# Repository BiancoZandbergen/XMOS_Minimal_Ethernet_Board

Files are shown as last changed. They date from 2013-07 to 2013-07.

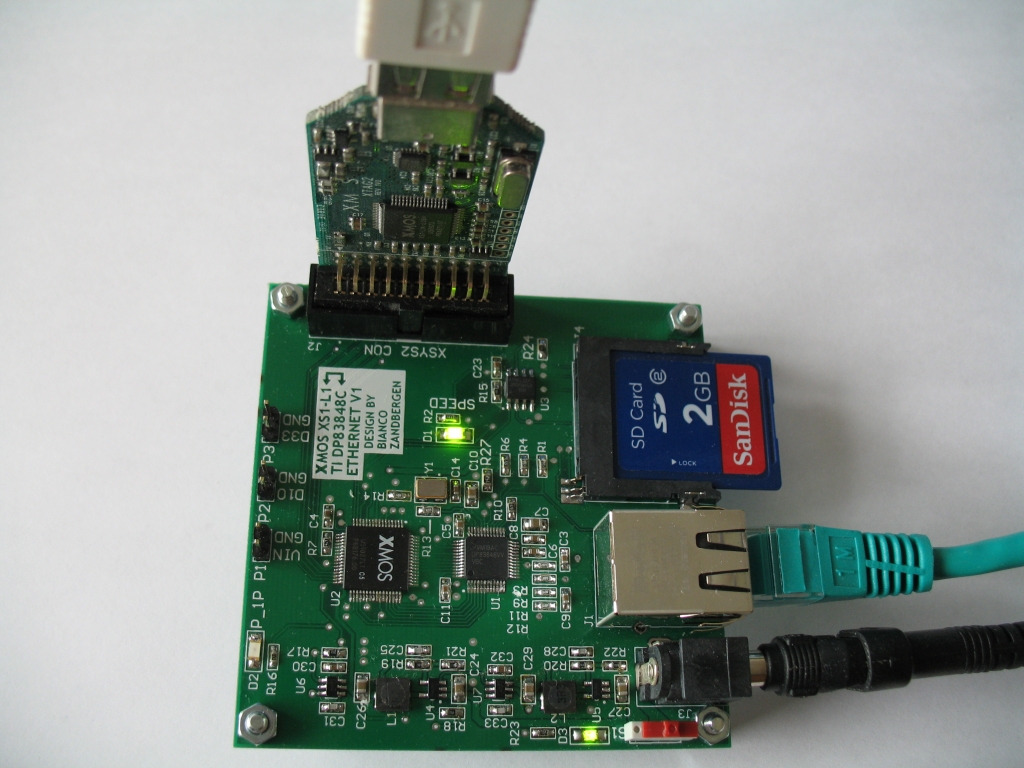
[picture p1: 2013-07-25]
images/board3.jpg

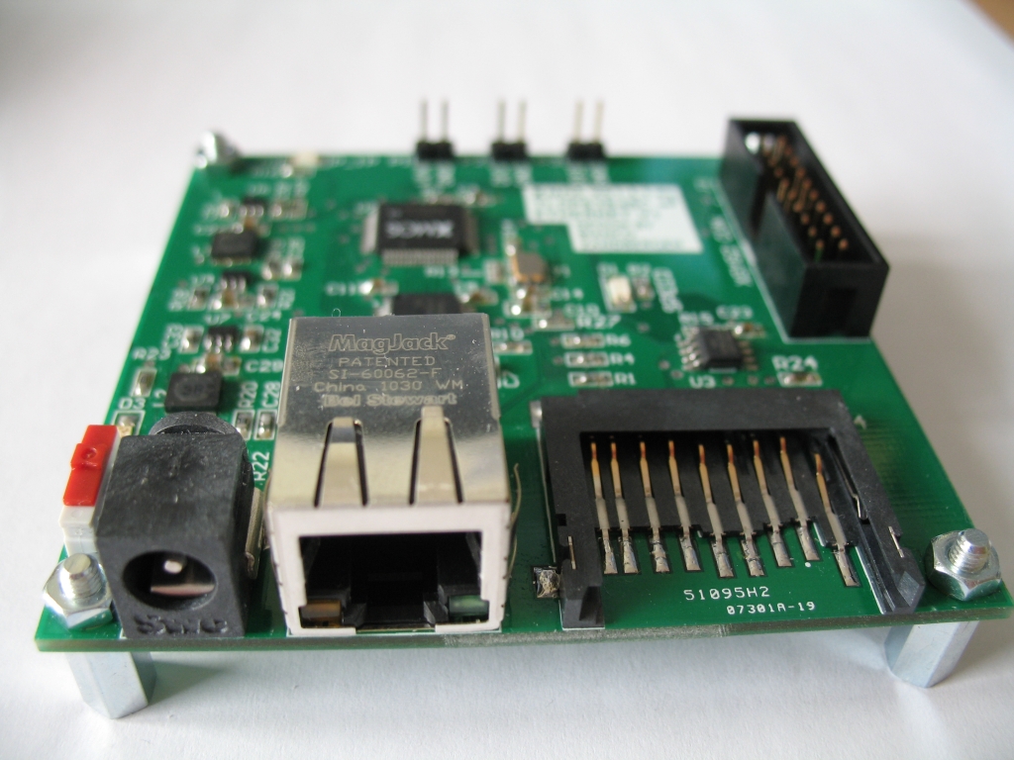
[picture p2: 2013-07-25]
images/board2.jpg

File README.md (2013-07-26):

XMOS Minimal Ethernet Board
===========================

XMOS XS1-L1 board with TI DP83848 Ethernet PHY
----------------------------------------------

This is a prototype board for the
Texas Instruments (Formerly National Semiconductor) DP83848C Ethernet PHY.

http://www.ti.com/product/dp83848c

The main advantage of this PHY over the SMSC LANx products
used in XMOS reference designs is that it is also available
in an easy to solder LQFP-48 package.

To use the PHY the following has to be changed in 
the ethernet module supplied by XMOS: module_ethernet\src\server\eth_phy.xc:

 #define PHY_ID 0x8001
 
 #define PHY_ADDRESS 0x01 (depends on the hardware design, 0x01 is for this board)

It is likely that the TI TLK110 PHY can also be used on this design,
they are pin compatible I believe, but I have yet to confirm it.

Please note that the pictures (except the 3D render) in the images folder
are from an earlier board revision.

<p align="center">
  
</p>

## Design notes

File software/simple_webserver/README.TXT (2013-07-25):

Simple test to check whether the hardware works.
Core frequency is 400 MHz.
Configured with static IP on 192.168.2.2 and MAC address 11:22:33:44:55:66.
Runs a webserver on port 80. Responds to ICMP ping packets.
Flashes the LED.

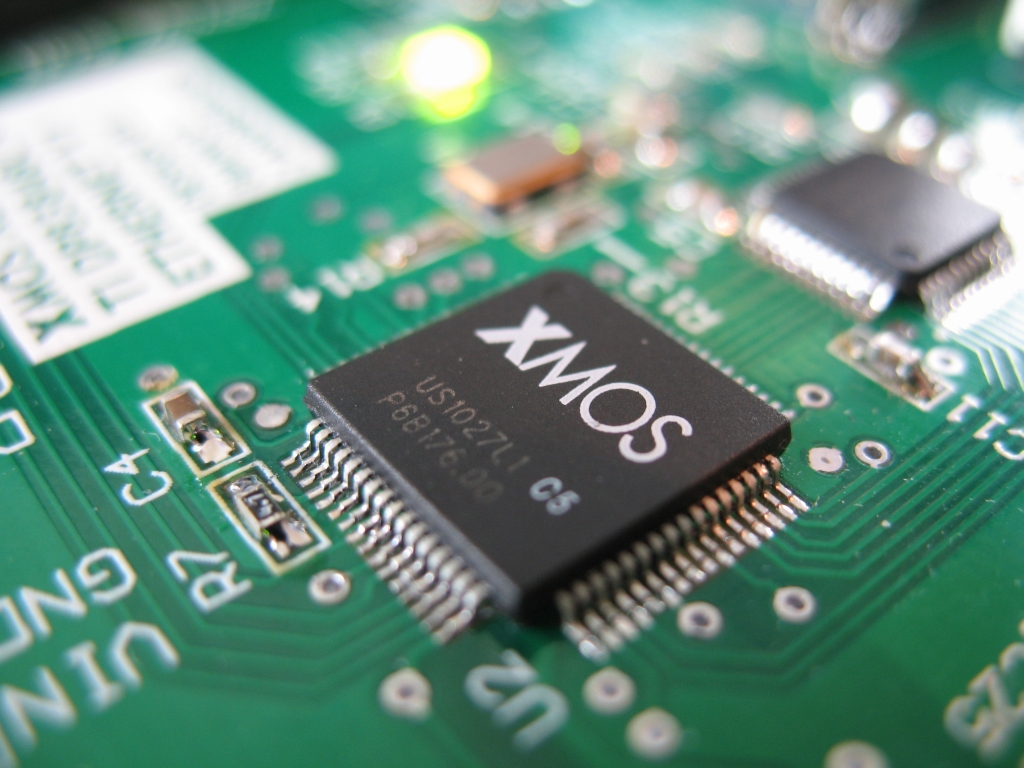
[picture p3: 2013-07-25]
images/board4.jpg

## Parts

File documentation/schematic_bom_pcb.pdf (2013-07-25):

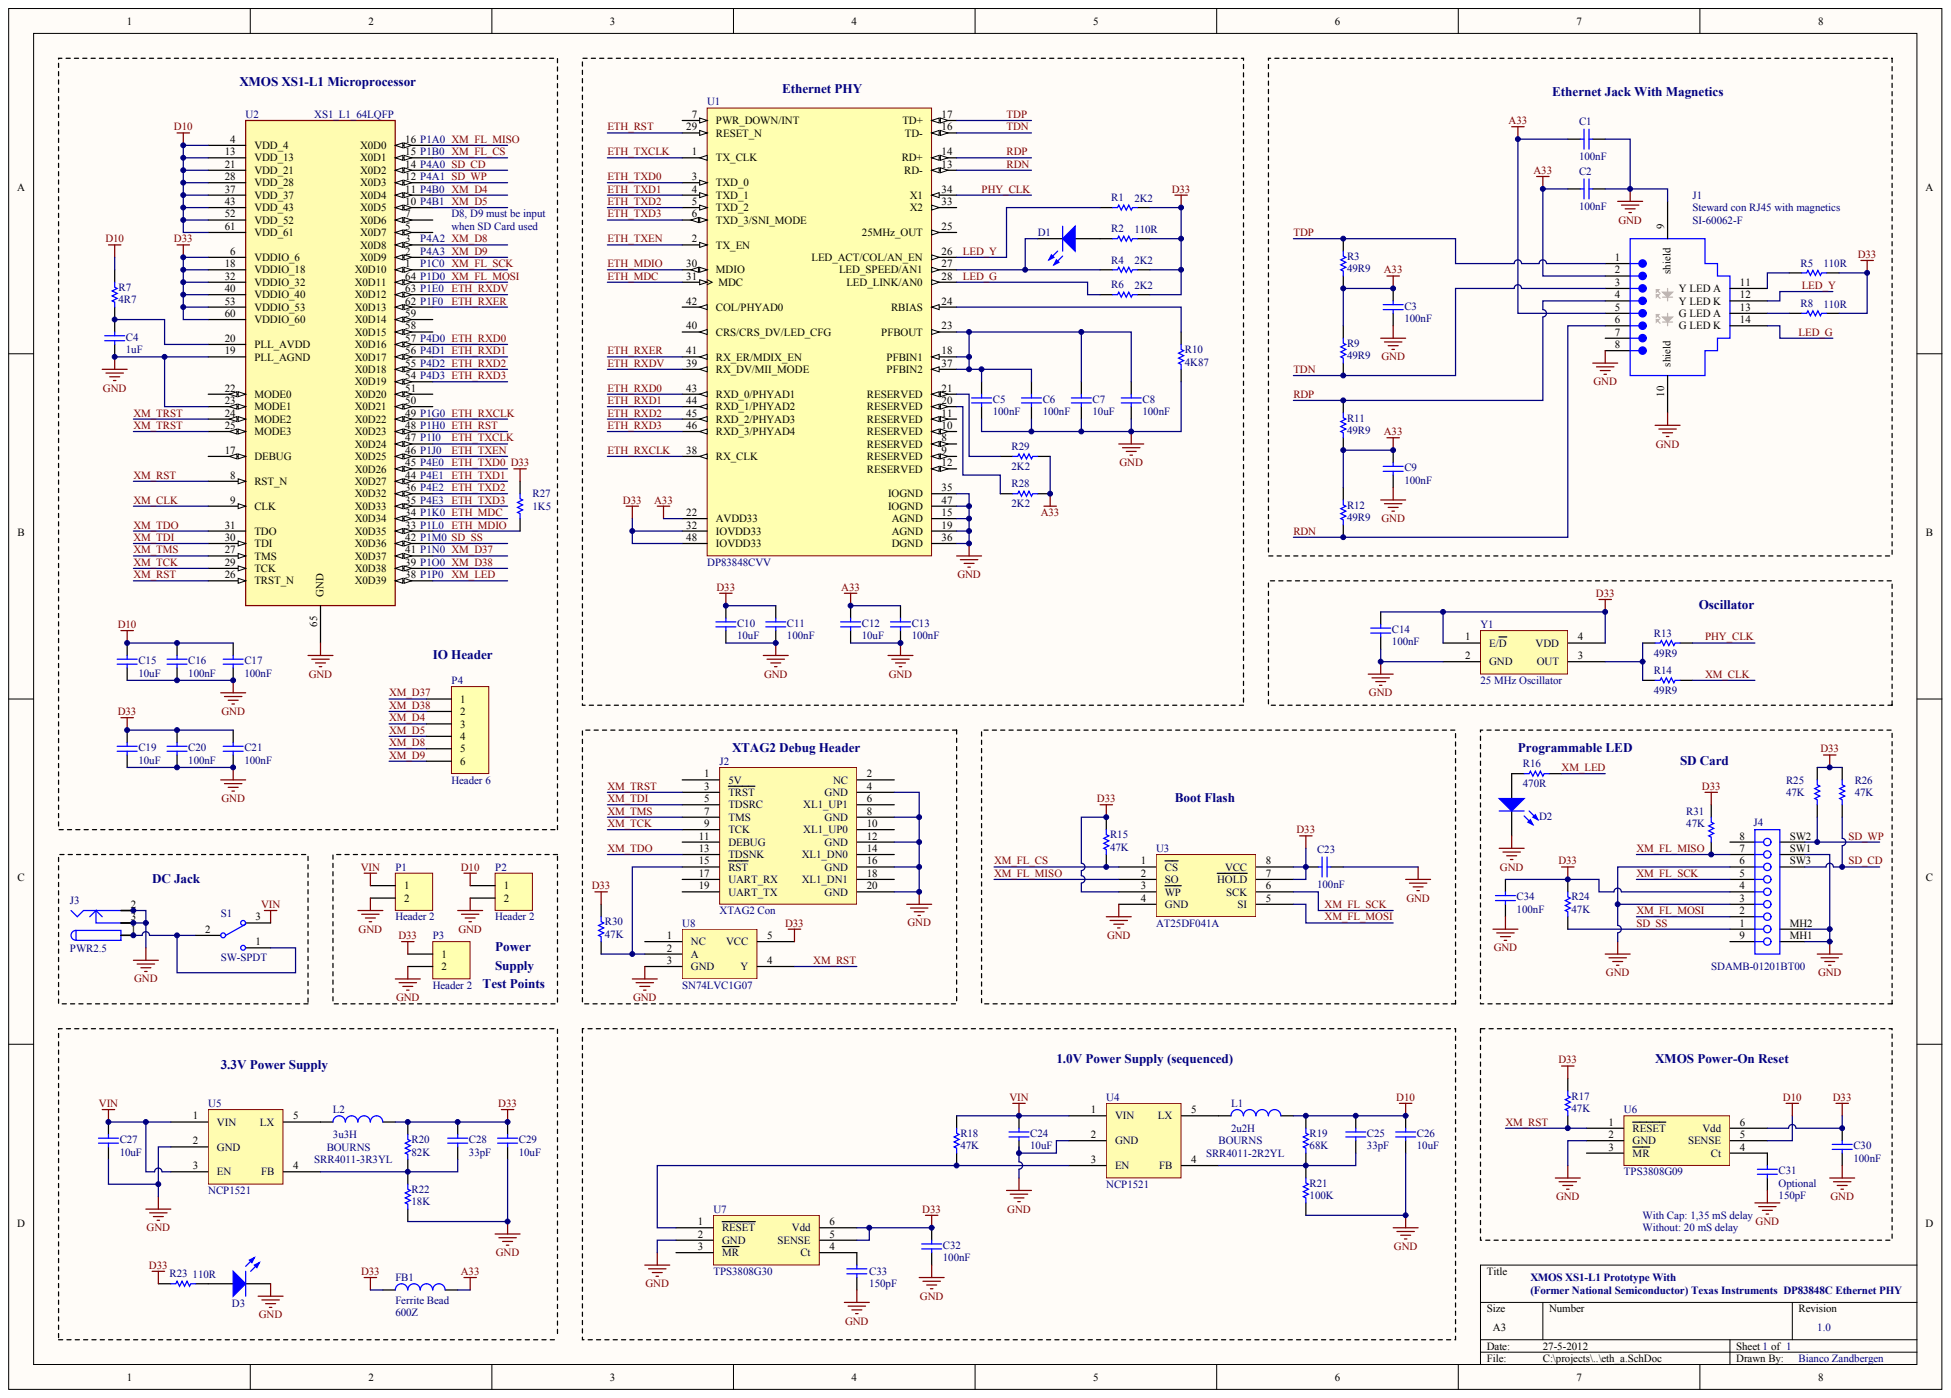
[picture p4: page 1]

Ethernet PHY XMOS XS1-L1 Microprocessor

Ethernet Jack With Magnetics

XMOS Power-On Reset

With Cap: 1,35 mS delay
Without: 20 mS delay

XMOS XS1-L1 Prototype With
(Former National Semiconductor) Texas Instruments DP83848C Ethernet PHY

Bill of Materials | XMOS XS1-L1 DP83848C Ethernet PHY Prototype
Source Data From: | | eth_a.SchDoc
Project: | | eth_a.PrjPCB
Variant: | | None
Creation Date: | 27-5-2012 | 14:40:45
Print Date: | 27-May-12 | ########
Description | Value | Quantity | Designator | Footprint | Manufacturer | ProductCode | Vendor | VendorCode | Price | Subtotal
4Mbit SPI Flash | | 1 | U3 | SOIC150-8_M | ATMEL | AT25DF041A-SSH-B | Farnell | 1715441 | 1,60 | 1,60
Buck Converter | | 2 | U4, U5 | SOT23-5 | ON SEMICONDUCTOR | NCP1521BSNT1G | Farnell | 1432258 | 1,58 | 3,16
Buffer (open drain output) | | 1 | U8 | SOT23-5 | TEXAS INSTRUMENTS | SN74LVC1G07DBV | Farnell | 1102969 | 0,47 | 0,47
Capacitor | 100nF | 18 | C1, C2, C3, C5, C6, C8, C9, C11, C13, C14,
| | | C16, C17, C20, C21, C23, C30, C32, C34 | 1608[0603]_CAP | MURATA | GRM188R71H104KA93D | Farnell | 8820023 | 0,05 | 0,90
Capacitor | 10uF | 9 | C7, C10, C12, C15, C19, C24, C26, C27, C29 | 2012[0805]_CAP | AVX | 0805ZD106KAT2A | Farnell | 1833812 | 0,12 | 1,08
Capacitor | 150pF | 2 | C31, C33 | 1608[0603]_CAP | MURATA | GRM1885C1H151JA01D | Farnell | 8819874 | 0,05 | 0,10
Capacitor | 1uF | 1 | C4 | 1608[0603]_CAP | KEMET | C0603C105K4RACTU | Farnell | 1650837 | 0,17 | 0,17
Capacitor | 33pF | 2 | C25, C28 | 1608[0603]_CAP | MURATA | GRM1885C1H330JA01D | Farnell | 1828910 | 0,03 | 0,06
Crystal Oscillator SMD 5mm x 3.2mm | 25 MHz | 1 | Y1 | OSC_32_50 | TXC | 7C-25.000MBB-T | Farnell | 1842032 | 3,21 | 3,21
Ferrite Bead | 600Z | 1 | FB1 | 1608[0603]_FB | MURATA | BLM18AG601SN1D | Farnell | 1515679 | 0,06 | 0,06
Header, 2-Pin | | 3 | P1, P2, P3 | HDR1X2 | | | | | 0,00 | 0,00
Header, 6-Pin | | 1 | P4 | HDR1X6 | | | | | 0,00 | 0,00
Inductor | 2u2H | 1 | L1 | BOURNS_SRR4011 | BOURNS | SRR4011-2R2YL | Farnell | 1828153 | 1,04 | 1,04
Inductor | 3u3H | 1 | L2 | BOURNS_SRR4011 | BOURNS | SRR4011-3R3YL | Farnell | 1828154 | 0,27 | 0,27
Low Voltage Power Supply Connector | | 1 | J3 | KLD-0202 | SWITCHCRAFT | RAPC722X | Farnell | 1608727 | 1,58 | 1,58
Power on Reset controller 0.9V | | 1 | U6 | SOT23-6 | TEXAS INSTRUMENTS | TPS3808G09DBVT | Farnell | 1755527 | 2,45 | 2,45
Power on Reset controller 3.0V | | 1 | U7 | SOT23-6 | TEXAS INSTRUMENTS | TPS3808G30DBVT | Farnell | 1755533 | 2,45 | 2,45
Resistor | 100K | 1 | R21 | 1608[0603]_RES | VISHAY DRALORIC | CRCW0603100KFKEA | Farnell | 1469649 | 0,02 | 0,02
Resistor | 110R | 4 | R2, R5, R8, R23 | 1608[0603]_RES | PANASONIC | ERJ3GEYJ111V | Farnell | 2059576 | 0,01 | 0,04
Resistor | 18K | 1 | R22 | 1608[0603]_RES | VISHAY DRALORIC | CRCW060318K0FKEAHP | Farnell | 1738921 | 0,04 | 0,04
Resistor | 1K5 | 1 | R27 | 1608[0603]_RES | PANASONIC | ERJ3GEYJ152V | Farnell | 2059606 | 0,01 | 0,01
Resistor | 2K2 | 5 | R1, R4, R6, R28, R29 | 1608[0603]_RES | YAGEO | RE0603DR-072K2L | Farnell | 1840583 | 0,01 | 0,05
Resistor | 470R | 1 | R16 | 1608[0603]_RES | BOURNS | CR0603-JW-471GLF | Farnell | 2008354 | 0,02 | 0,02
Resistor | 47K | 8 | R15, R17, R18, R24, R25, R26, R30, R31 | 1608[0603]_RES | VISHAY DRALORIC | CRCW060347K0FKEA | Farnell | 1469811 | 0,02 | 0,16
Resistor | 49R9 | 6 | R3, R9, R11, R12, R13, R14 | 1608[0603]_RES | SUSUMU | RR0816Q-49R9-D-68R | Farnell | 1612045 | 0,02 | 0,12
Resistor | 4K87 | 1 | R10 | 1608[0603]_RES | MULTICOMP | MC 0.063W 0603 1% | Farnell | 1170858 | 0,02 | 0,02
Resistor | 4R7 | 1 | R7 | 1608[0603]_RES | PANASONIC | ERJ3GEYJ4R7V | Farnell | 2059539 | 0,01 | 0,01
Resistor | 68K | 1 | R19 | 1608[0603]_RES | PANASONIC | CRCW060368K0FKEA | Farnell | 1469832 | 0,02 | 0,02
Resistor | 82K | 1 | R20 | 1608[0603]_RES | VISHAY DRALORIC | CRCW060382K0FKEAHP | Farnell | 1738930 | 0,04 | 0,04
Right Angle,RJ45-Keyed, Flange Mount PCB Jack | | 1 | J1 | Steward Con RJ45 | STEWART CONNECTOR | SI-60062-F | Farnell | 1137983 | 5,21 | 5,21
Secure Digital Card Connector, Type A without Cover | | 1 | J4 | SDCARD-SDAMB-012 | MULTICOMP | SDAMB-01215BT00 | Farnell | 9186140 | 1,60 | 1,60
Single Port 10/100 Mb/s Ethernet PHY | | 1 | U1 | TSQFP50P900X900-48M | National Semiconductor | DP83848CVV | Farnell | 1286816 | 4,89 | 4,89
SMD LED 0805 | GREEN | 1 | D3 | 2012[0805]_LED | KINGBRIGHT | KPHCM-2012SGC-T | Farnell | 1686074 | 0,16 | 0,16
SMD LED 0805 | ORANGE | 2 | D1, D2 | 2012[0805]_LED | KINGBRIGHT | KPHCM-2012SECK | Farnell | 1686068 | 0,16 | 0,32
SPDT Switch | | 1 | S1 | SIP-3 | EAO | 09.03201.02 | Farnell | 1608080 | 1,00 | 1,00
XMOS XS1-L1 Microprocessor | | 1 | U2 | XMOS_QFP50P1200X120
| | | | 0X160-65N | XMOS | XS1-L01A-LQ64-C5 | Digikey | 880-1032-ND | 6,65 | 6,65
XTAG2 Connector | | 1 | J2 | IDC2.54-V20D | TYCO | 2-1634688-0 | Farnell | 8395942 | 0,91 | 0,91
| | _______+ | | | | | | | | _______+
| | 87 | | | | | | | EUR | 39,89

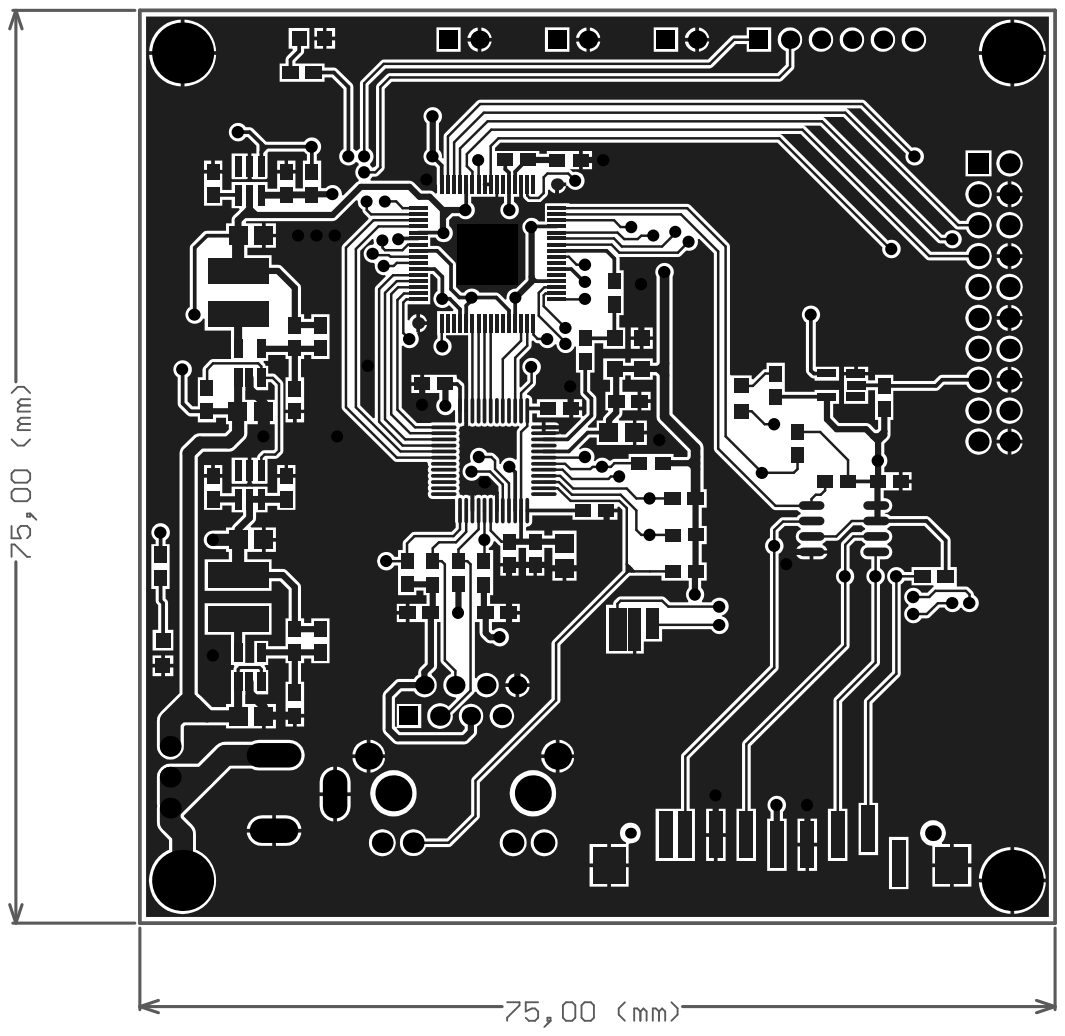
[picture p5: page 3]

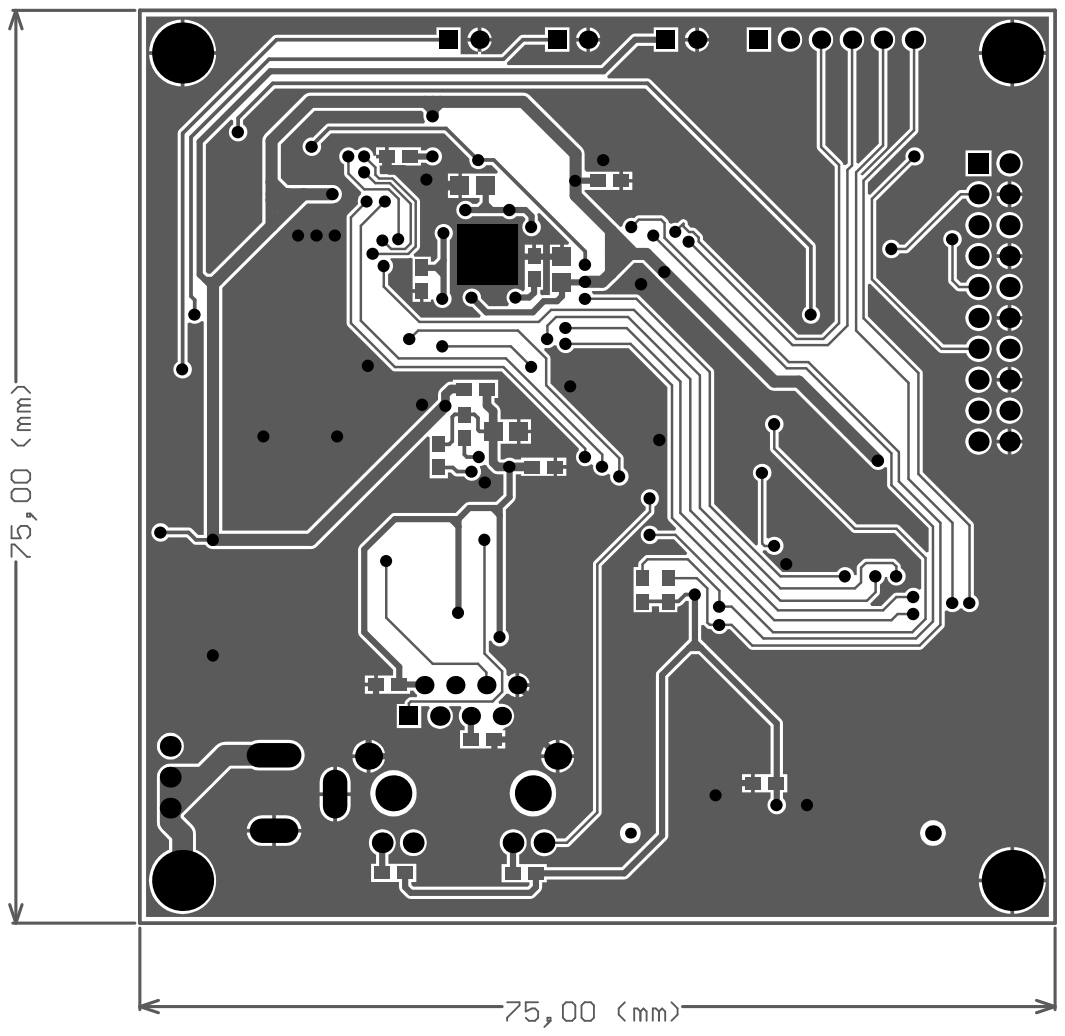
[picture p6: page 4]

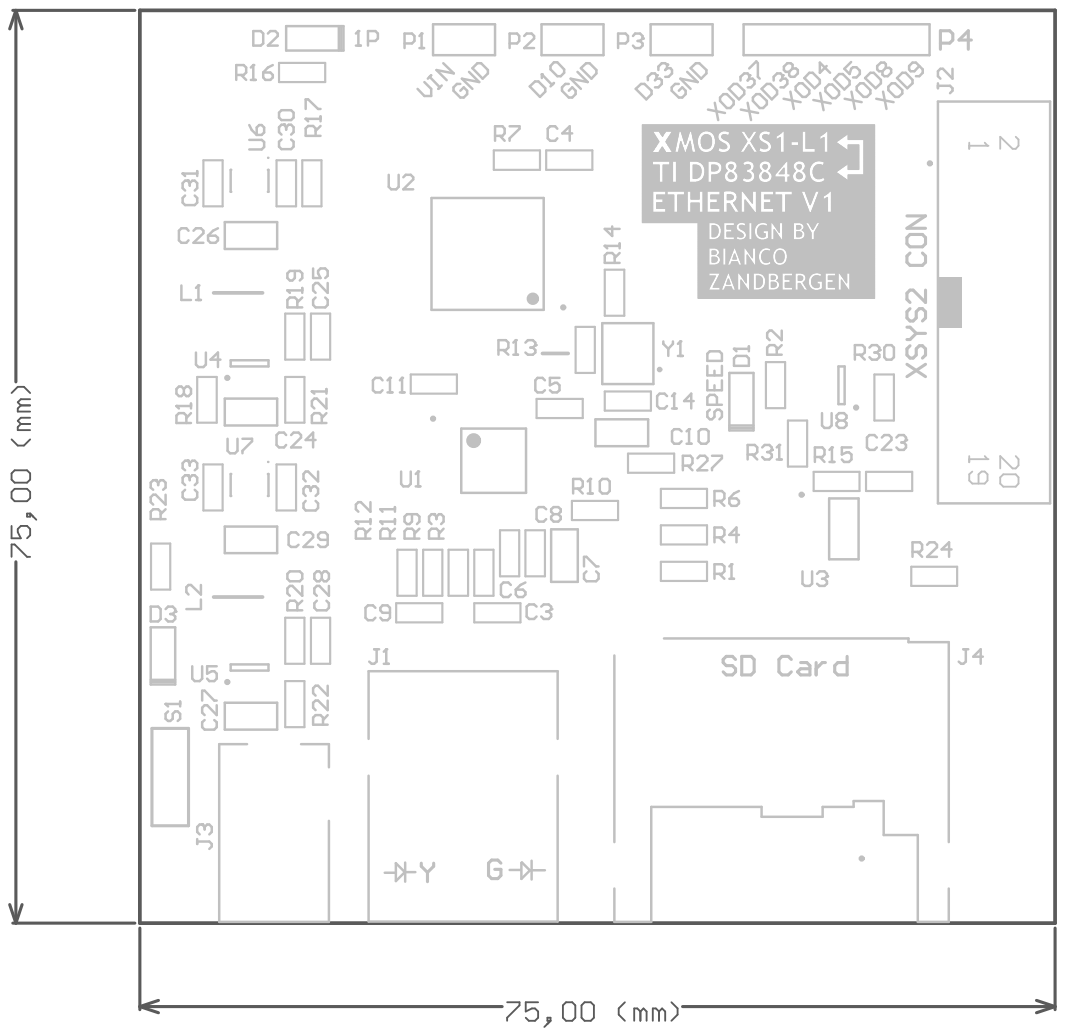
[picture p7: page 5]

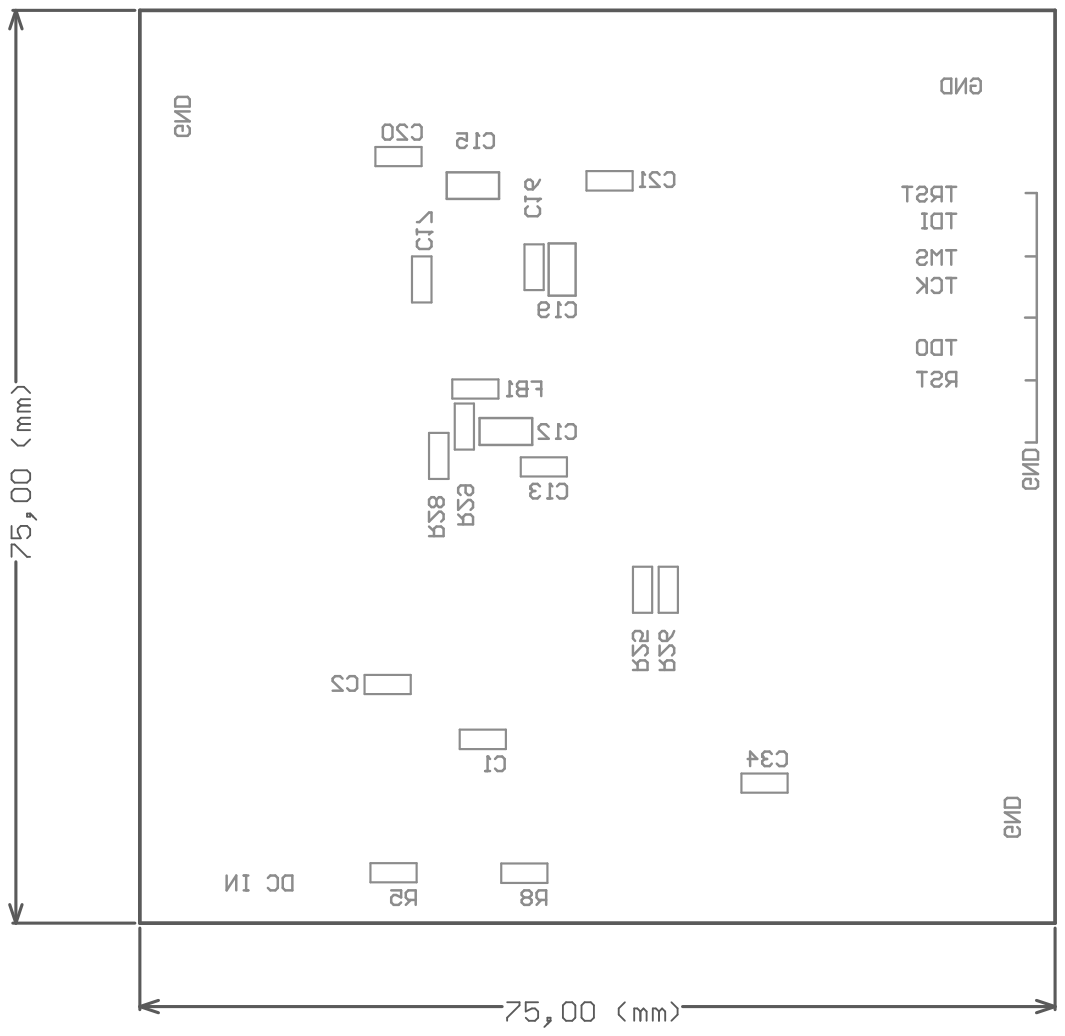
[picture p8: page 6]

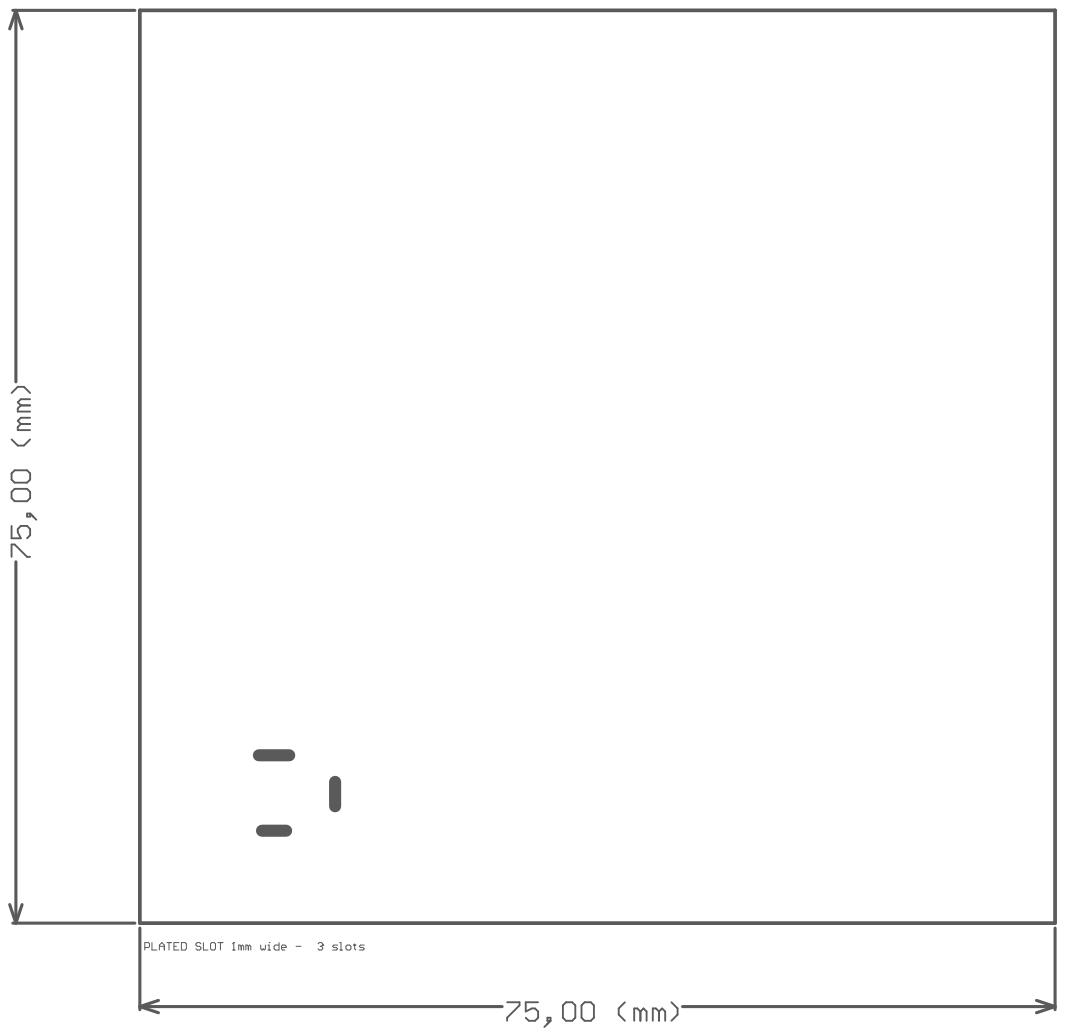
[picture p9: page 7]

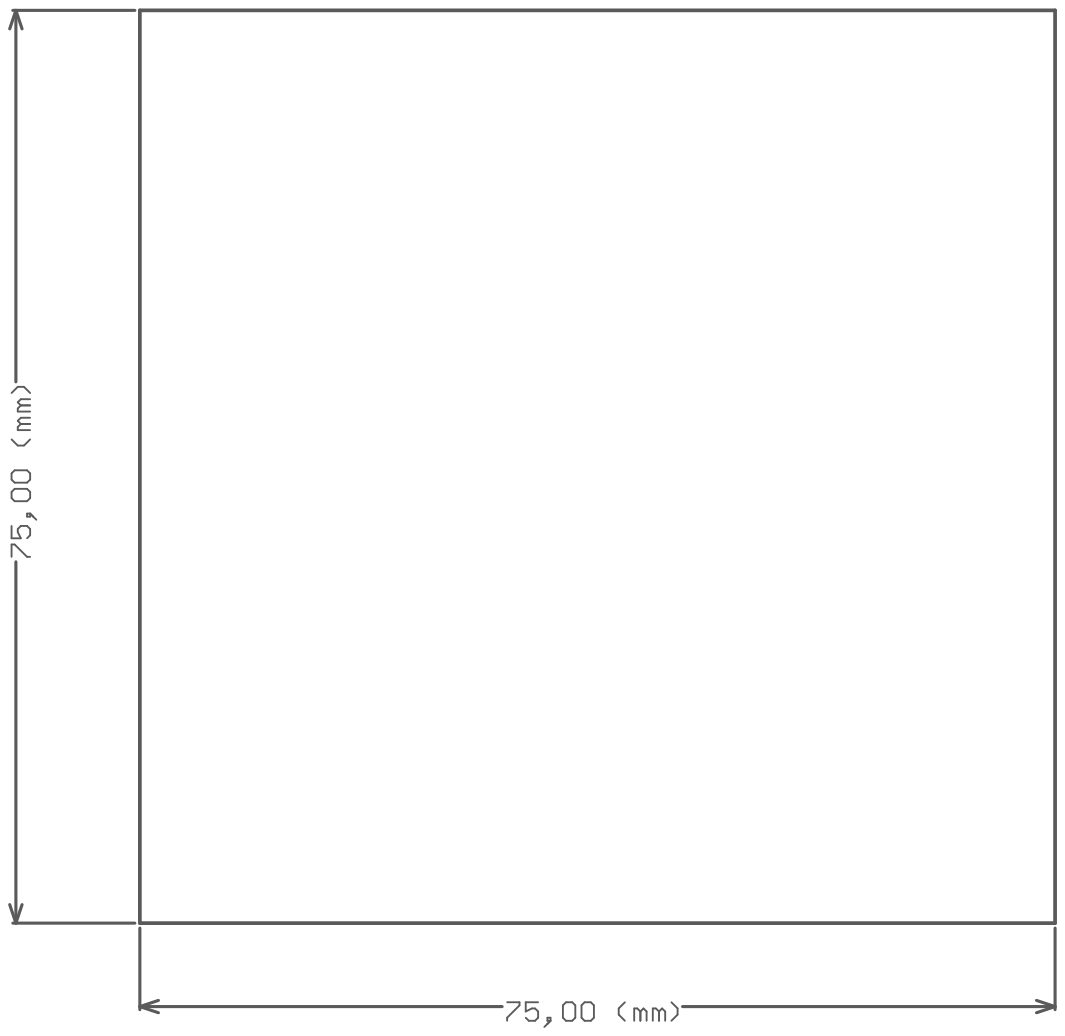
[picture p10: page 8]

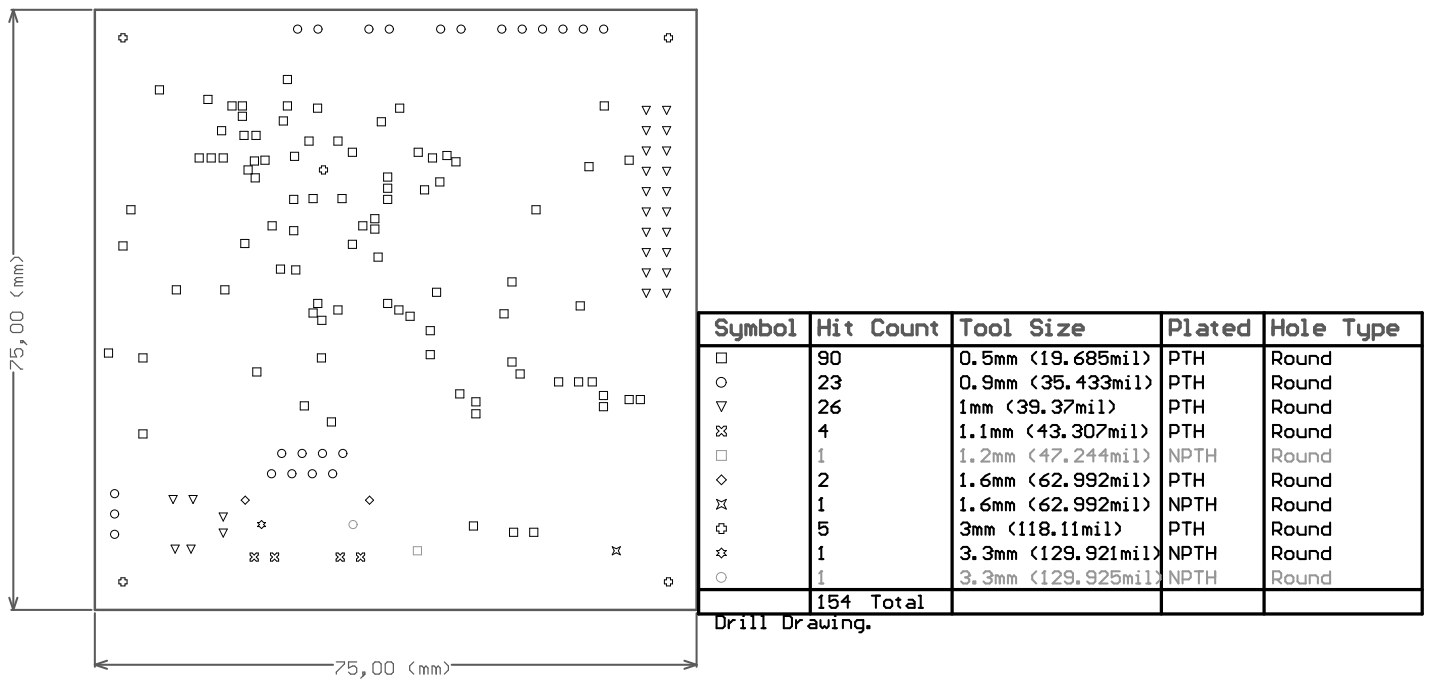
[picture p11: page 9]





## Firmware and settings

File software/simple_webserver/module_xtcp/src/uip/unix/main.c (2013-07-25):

// Copyright (c) 2011, XMOS Ltd, All rights reserved
// This software is freely distributable under a derivative of the
// University of Illinois/NCSA Open Source License posted in
// LICENSE.txt and at <http://github.xcore.com/>


/*
 * Copyright (c) 2001, Adam Dunkels.
 * All rights reserved.
 *
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
 * This file is part of the uIP TCP/IP stack.
 *
 * $Id: main.c,v 1.16 2006/06/11 21:55:03 adam Exp $
 *
 */


#include "uip.h"
#include "uip_arp.h"
#include "tapdev.h"

#include "timer.h"

#define BUF ((struct uip_eth_hdr *)&uip_buf[0])

#ifndef NULL
#define NULL (void *)0
#endif /* NULL */

/*---------------------------------------------------------------------------*/
int
main(void)
{
  int i;
  uip_ipaddr_t ipaddr;
  struct uip_timer periodic_timer, arp_timer;

  timer_set(&periodic_timer, CLOCK_SECOND / 2);
  timer_set(&arp_timer, CLOCK_SECOND * 10);
  
  tapdev_init();
  uip_init();

  uip_ipaddr(ipaddr, 192,168,0,2);
  uip_sethostaddr(ipaddr);
  uip_ipaddr(ipaddr, 192,168,0,1);
  uip_setdraddr(ipaddr);
  uip_ipaddr(ipaddr, 255,255,255,0);
  uip_setnetmask(ipaddr);

  httpd_init();
  
  /*  telnetd_init();*/
  
  /*  hello_world_init();*/

  /*  {
      u8_t mac[6] = {1,2,3,4,5,6};
      dhcpc_init(&mac, 6);
      }*/
  
  /*uip_ipaddr(ipaddr, 127,0,0,1);
  smtp_configure("localhost", ipaddr);
  SMTP_SEND("adam@sics.se", NULL, "uip-testing@example.com",
	    "Testing SMTP from uIP",
	    "Test message sent by uIP\r\n");*/

  /*
    webclient_init();
    resolv_init();
    uip_ipaddr(ipaddr, 195,54,122,204);
    resolv_conf(ipaddr);
    resolv_query("www.sics.se");*/


  
  while(1) {
    uip_len = tapdev_read();
    if(uip_len > 0) {
      if(BUF->type == htons(UIP_ETHTYPE_IP)) {
	uip_arp_ipin();
	uip_input();
	/* If the above function invocation resulted in data that
	   should be sent out on the network, the global variable
	   uip_len is set to a value > 0. */
	if(uip_len > 0) {
	  uip_arp_out();
	  tapdev_send();
	}
      } else if(BUF->type == htons(UIP_ETHTYPE_ARP)) {
	uip_arp_arpin();
	/* If the above function invocation resulted in data that
	   should be sent out on the network, the global variable
	   uip_len is set to a value > 0. */
	if(uip_len > 0) {
	  tapdev_send();
	}
      }

    } else if(timer_expired(&periodic_timer)) {
      timer_reset(&periodic_timer);
      for(i = 0; i < UIP_CONNS; i++) {
	uip_periodic(i);
	/* If the above function invocation resulted in data that
	   should be sent out on the network, the global variable
	   uip_len is set to a value > 0. */
	if(uip_len > 0) {
	  uip_arp_out();
	  tapdev_send();
	}
      }

#if UIP_UDP
      for(i = 0; i < UIP_UDP_CONNS; i++) {
	uip_udp_periodic(i);
	/* If the above function invocation resulted in data that
	   should be sent out on the network, the global variable
	   uip_len is set to a value > 0. */
	if(uip_len > 0) {
	  uip_arp_out();
	  tapdev_send();
	}
      }
#endif /* UIP_UDP */
      
      /* Call the ARP timer function every 10 seconds. */
      if(timer_expired(&arp_timer)) {
	timer_reset(&arp_timer);
	uip_arp_timer();
      }
    }
  }
  return 0;
}
/*---------------------------------------------------------------------------*/
void
uip_log(char *m)
{
  printf("uIP log message: %s\n", m);
}
void
resolv_found(char *name, u16_t *ipaddr)
{
  u16_t *ipaddr2;
  
  if(ipaddr == NULL) {
    printf("Host '%s' not found.\n", name);
  } else {
    printf("Found name '%s' = %d.%d.%d.%d\n", name,
	   htons(ipaddr[0]) >> 8,
	   htons(ipaddr[0]) & 0xff,
	   htons(ipaddr[1]) >> 8,
	   htons(ipaddr[1]) & 0xff);
    /*    webclient_get("www.sics.se", 80, "/~adam/uip");*/
  }
}
#ifdef __DHCPC_H__
void
dhcpc_configured(const struct dhcpc_state *s)
{
  uip_sethostaddr(s->ipaddr);
  uip_setnetmask(s->netmask);
  uip_setdraddr(s->default_router);
  resolv_conf(s->dnsaddr);
}
#endif /* __DHCPC_H__ */
void
smtp_done(unsigned char code)
{
  printf("SMTP done with code %d\n", code);
}
void
webclient_closed(void)
{
  printf("Webclient: connection closed\n");
}
void
webclient_aborted(void)
{
  printf("Webclient: connection aborted\n");
}
void
webclient_timedout(void)
{
  printf("Webclient: connection timed out\n");
}
void
webclient_connected(void)
{
  printf("Webclient: connected, waiting for data...\n");
}
void
webclient_datahandler(char *data, u16_t len)
{
  printf("Webclient: got %d bytes of data.\n", len);
}
/*---------------------------------------------------------------------------*/

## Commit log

2013-07-25 project as released in 2012 on http://www.xcore.com/projects/xs1-l1-ti-dp83848-ethernet-phy-prototype
    [eth_a.PcbDoc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]
2013-07-25 add board support package XN file
